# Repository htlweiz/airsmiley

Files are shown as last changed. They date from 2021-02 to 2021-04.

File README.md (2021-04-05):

# Air Smiley: eCO2 measurement box
A small-ish and simple box to measure
- eCO2 with a CCS811 sensor
- Temperature and Humidity with a DHT22 sensor

using a Wemos D1 mini (or clone) with visualization on a
- 0.96" I2C OLED (SSD1306 based)
- NeoPixel compatible RGB LED ring (WS2812B)

The thresholds are set according to [REHVA's recommendations for schools](https://www.rehva.eu/fileadmin/user_upload/REHVA_COVID-19_guidance_document_School_guidance_25112020.pdf).

## User Manual
A (german) user manual is available [here](AIR%20SMILEY.pdf).

## Burn-In
For full sensor accuracy, according to the [datasheet](https://www.sciosense.com/wp-content/uploads/2020/01/CCS811-Datasheet.pdf), the device first needs a "burn-in" phase of 48 operating hours. 

## Run-In
After the "burn-in" phase, the values are considered accurate after a "run-in" time of 20 minutes after power on. Make sure you expose the sensor to clean air throughout the run-in or shortly afterwards to correctly set the baseline (low CO2) for correct sensor readings.

## Flashing
- Install the newest [ESP8266 support](https://www.heise.de/ct/artikel/Arduino-IDE-installieren-und-fit-machen-fuer-ESP8266-und-ESP32-4130814.html)
- Add the following libraries (using the built-in library manager, *Tools –> Manage Libraries...*)
  - NeoPixelBus by Makuna (LGPL-3.0 License)
  - Adafruit CCS811 (MIT License)
  - DHT sensor library by Adafruit (MIT License)
  - Adafruit SSD1306 (BSD License)

## PCB
The PCB has been designed with KiCad and uses the corresponding [libraries](https://kicad.org/libraries/) which are available under the [Creative Commons CC-BY-SA 4.0 License](https://creativecommons.org/licenses/by-sa/4.0/legalcode). Additionally, a [footprint](https://github.com/rubienr/wemos-d1-mini-kicad) made by [rubienr](https://github.com/rubienr) is used.

The PCB is designed to be screwed into a case available at [aliexpress](https://de.aliexpress.com/item/4000068796385.html?spm=a2g0s.9042311.0.0.52614c4dDeY8Wv).

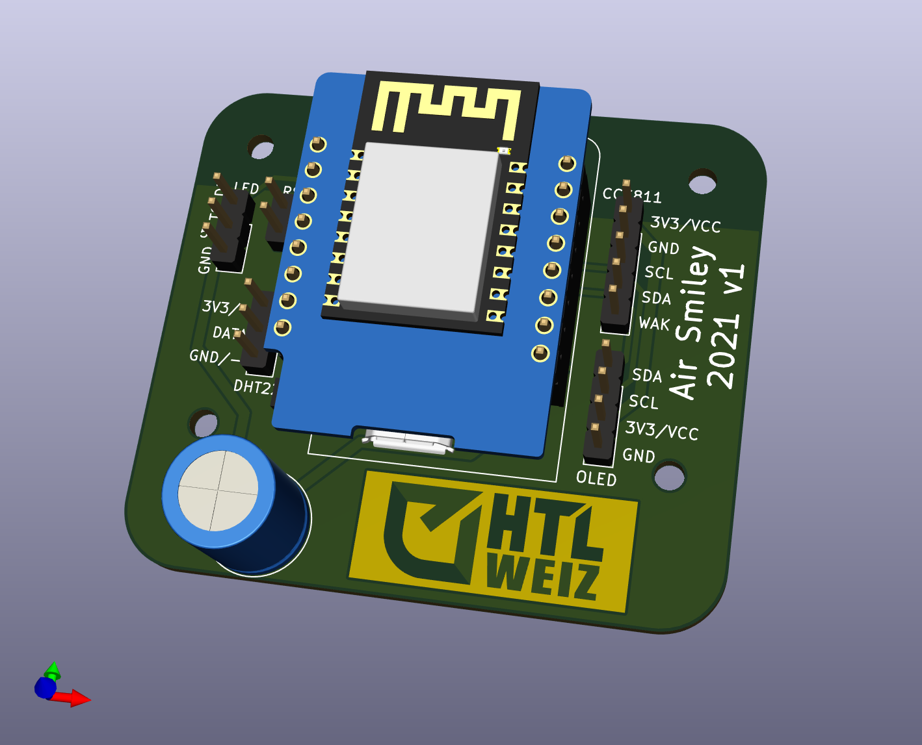
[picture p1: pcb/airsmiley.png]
PCB PCB rendering

1

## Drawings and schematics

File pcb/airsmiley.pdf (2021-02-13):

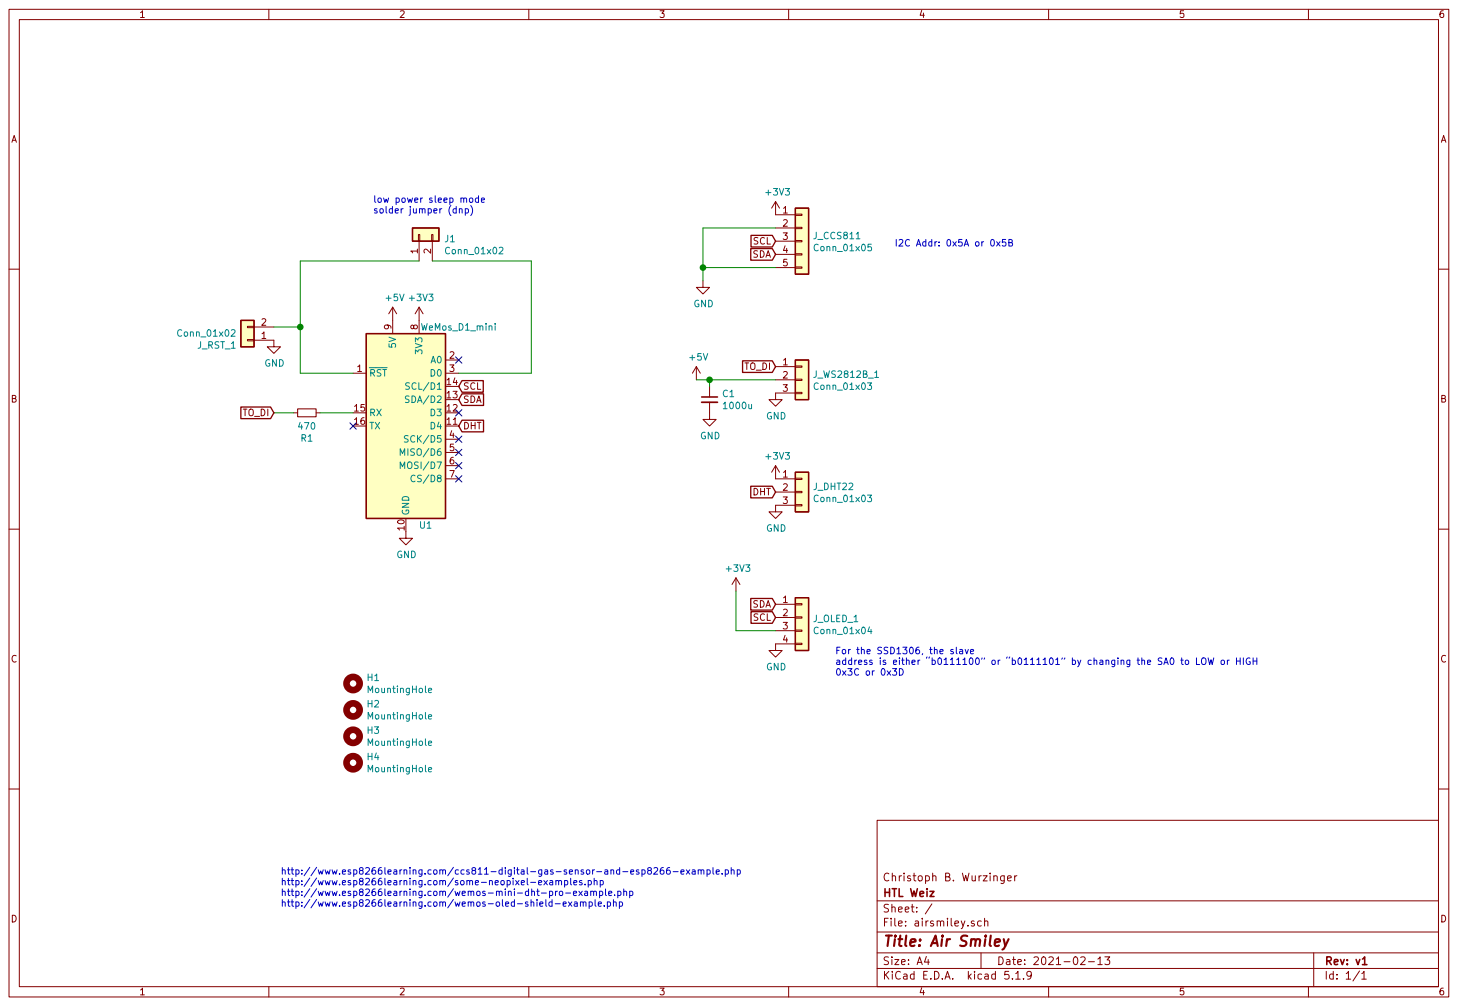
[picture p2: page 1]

low power sleep mode

File: airsmiley.sch Sheet: / HTL Weiz Christoph B. Wurzinger R1

address is either b0111100 or b0111101 by changing the SA0 to LOW or HIGH

http://www.esp8266learning.com/ccs811-digital-gas-sensor-and-esp8266-example.php
http://www.esp8266learning.com/some-neopixel-examples.php
http://www.esp8266learning.com/wemos-mini-dht-pro-example.php
http://www.esp8266learning.com/wemos-oled-shield-example.php

Id: 1/1 Title: Air Smiley

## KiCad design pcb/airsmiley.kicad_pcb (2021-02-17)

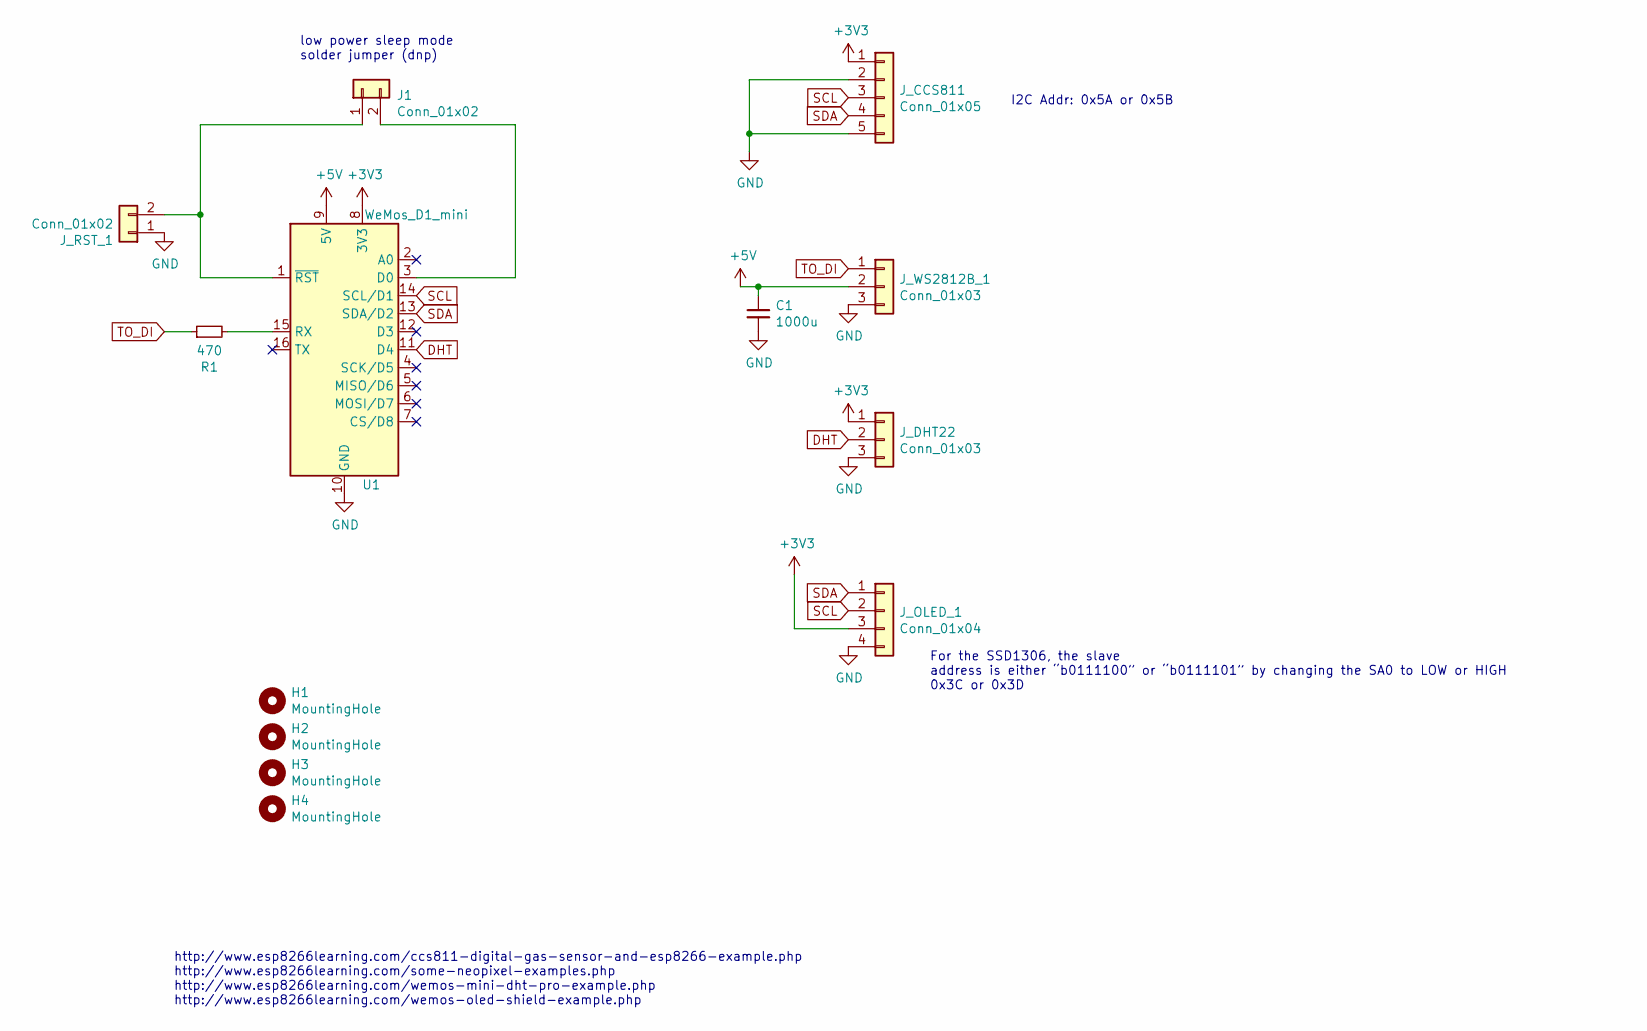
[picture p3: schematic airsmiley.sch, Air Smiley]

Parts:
C1: 1000u; C_Radial_D10.0mm_H12.5mm_P5.00mm
H1, H2, H3, H4: MountingHole; MountingHole_2.7mm_M2.5
J1: Conn_01x02; PinHeader_1x02_P2.54mm_Vertical
J_CCS811: Conn_01x05; PinHeader_1x05_P2.54mm_Vertical
J_DHT22: Conn_01x03; PinHeader_1x03_P2.54mm_Vertical
J_OLED_1: Conn_01x04; PinHeader_1x04_P2.54mm_Vertical
J_RST_1: Conn_01x02; PinHeader_1x02_P2.54mm_Vertical
J_WS2812B_1: Conn_01x03; PinHeader_1x03_P2.54mm_Vertical
R1: 470; R_Axial_DIN0207_L6.3mm_D2.5mm_P10.16mm_Horizontal
U1: WeMos_D1_mini; WEMOS_D1_mini_light

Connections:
+3V3: J_CCS811.1, J_DHT22.1, J_OLED_1.3, U1.8 (3V3)
+5V: C1.1, J_WS2812B_1.2, U1.9 (5V)
DHT: J_DHT22.2, U1.11 (D4)
GND: C1.2, J_CCS811.2, J_CCS811.5, J_DHT22.3, J_OLED_1.4, J_RST_1.1, J_WS2812B_1.3, U1.10 (GND)
unnamed: J1.1, J_RST_1.2, U1.1 (~RST)
unnamed: J1.2, U1.3 (D0)
unnamed: R1.2, U1.15 (RX)
SCL: J_CCS811.3, J_OLED_1.2, U1.14 (SCL/D1)
SDA: J_CCS811.4, J_OLED_1.1, U1.13 (SDA/D2)
TO_DI: J_WS2812B_1.1, R1.1

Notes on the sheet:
http://www.esp8266learning.com/ccs811-digital-gas-sensor-and-esp8266-example.php http://www.esp8266learning.com/some-neopixel-examples.php http://www.esp8266learning.com/wemos-mini-dht-pro-example.php http://www.esp8266learning.com/wemos-oled-shield-example.php
low power sleep mode solder jumper (dnp)
I2C Addr: 0x5A or 0x5B
For the SSD1306, the slave address is either “b0111100” or “b0111101” by changing the SA0 to LOW or HIGH 0x3C or 0x3D

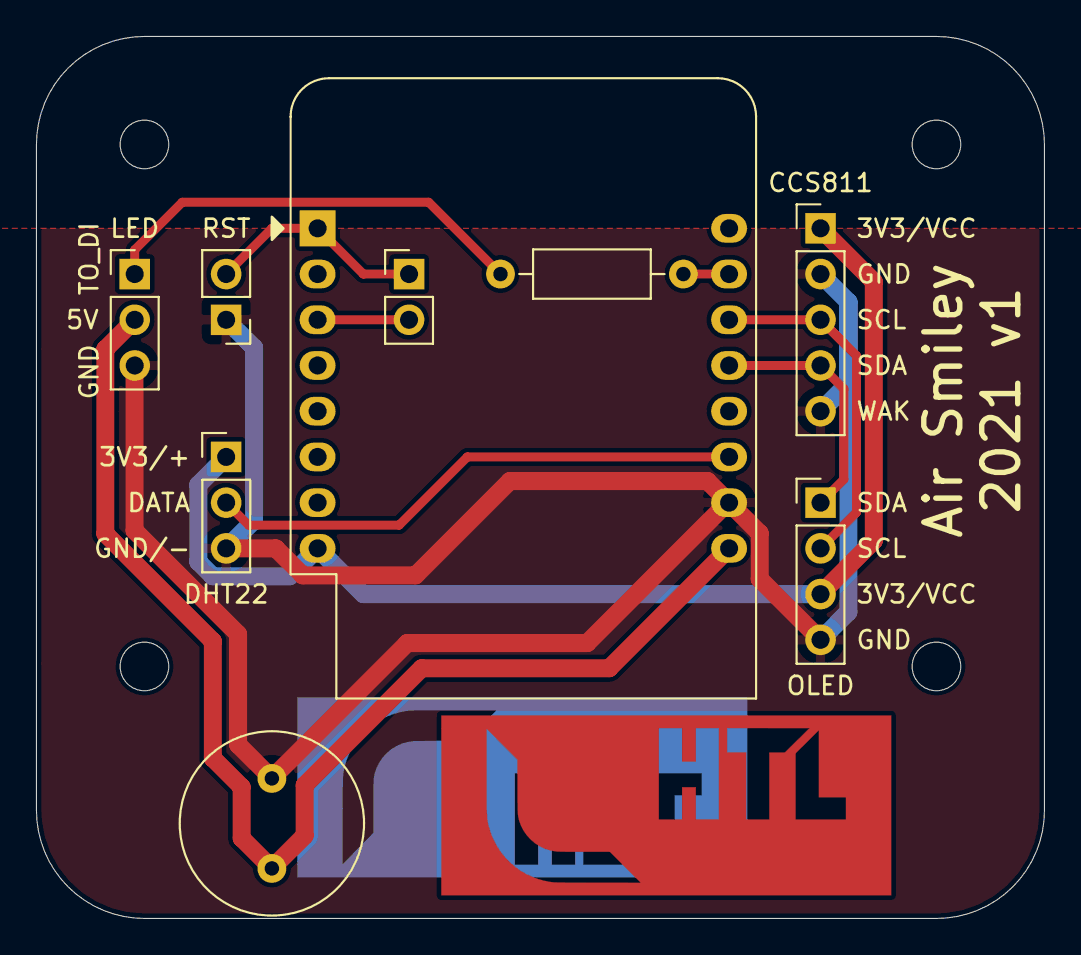
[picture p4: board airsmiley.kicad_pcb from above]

Board: 2 copper layers, 56.0 x 49.0 mm, 15 parts (1 on the bottom side), 10 nets.

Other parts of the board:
Ref**: Val**; logo
Ref**#2: Val**; logo

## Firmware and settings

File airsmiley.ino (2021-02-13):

/*
Copyright 2021 HTL Weiz

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
THE SOFTWARE IS PROVIDED "AS IS", WITHOUT WARRANTY OF ANY KIND, EXPRESS OR
IMPLIED, INCLUDING BUT NOT LIMITED TO THE WARRANTIES OF MERCHANTABILITY,
FITNESS FOR A PARTICULAR PURPOSE AND NONINFRINGEMENT. IN NO EVENT SHALL THE
AUTHORS OR COPYRIGHT HOLDERS BE LIABLE FOR ANY CLAIM, DAMAGES OR OTHER
LIABILITY, WHETHER IN AN ACTION OF CONTRACT, TORT OR OTHERWISE, ARISING FROM,
OUT OF OR IN CONNECTION WITH THE SOFTWARE OR THE USE OR OTHER DEALINGS IN THE
SOFTWARE.
*/

#include "Adafruit_CCS811.h"
#include "DHT.h"
#include <Adafruit_GFX.h>
#include <Adafruit_SSD1306.h>
#include <NeoPixelBus.h>
#include <SPI.h>
#include <Wire.h>

/***********************************************************************
   CO2 Thresholds (ppm).
***********************************************************************/
// Recommendation from REHVA (Federation of European Heating, Ventilation and
// Air Conditioning associations, rehva.eu) for preventing COVID-19 aerosol
// spread especially in schools:
// - warn: 800 (yellow/orange), critical: 1000 (red)
// (https://www.rehva.eu/fileadmin/user_upload/REHVA_COVID-19_guidance_document_School_guidance_25112020.pdf)

#define CO2_WARN_PPM 800
#define CO2_CRITICAL_PPM 1000

/***********************************************************************
   LED ring: NeoPixelBus Setup
***********************************************************************/
const uint16_t PixelCount = 8;
const uint16_t colorSaturation = 10;

NeoPixelBus<NeoGrbFeature, Neo800KbpsMethod> ring(PixelCount, -1);

RgbColor red(colorSaturation, 0, 0);
RgbColor green(0, colorSaturation, 0);
RgbColor orange(colorSaturation, colorSaturation / 2, 0);
RgbColor white(colorSaturation);
RgbColor black(0);

/***********************************************************************
   eCO2 sensor: CCS811 Setup
***********************************************************************/
Adafruit_CCS811 ccs;

/***********************************************************************
   Temperature and Humidity sensor: DHT22 Setup
***********************************************************************/
#define DHTPIN 2
#define DHTTYPE DHT22

DHT dht(DHTPIN, DHTTYPE);

/***********************************************************************
   OLED display: SSD1306 Setup
***********************************************************************/
#define SCREEN_WIDTH 128 // OLED display width, in pixels
#define SCREEN_HEIGHT 64 // OLED display height, in pixels

// Declaration for an SSD1306 display connected to I2C (SDA, SCL pins)
#define OLED_RESET -1 // Reset pin # (or -1 if sharing Arduino reset pin)
Adafruit_SSD1306 display(SCREEN_WIDTH, SCREEN_HEIGHT, &Wire, OLED_RESET);

/***********************************************************************
   System Startup
***********************************************************************/
void setup() {
  Serial.begin(115200);
  Serial.println(F("\nStarting up"));

  Serial.println(F("Bringing up eCO2 sensor"));
  if (!ccs.begin(0x5a)) {
    Serial.println("FAILED to start eCO2 sensor! Please check your wiring.");
  }
  ccs.setDriveMode(CCS811_DRIVE_MODE_1SEC);

  Serial.println(F("Bringing up display"));
  if (!display.begin(SSD1306_SWITCHCAPVCC, 0x3C)) {
    Serial.println(F("FAILED display allocation"));
  }
  display.setRotation(2);
  display.clearDisplay();
  display.display();

  Serial.println(F("Bringing up LEDs"));
  ring.Begin();
  for (int i = 0; i < PixelCount; i++) {
    ring.SetPixelColor(i, white);
  }
  ring.Show();

  Serial.println(F("Bringing up temperaturea and humidity sensor"));
  dht.begin();

  Serial.println(F("Setup complete."));
}

/***********************************************************************
   Main Loop
***********************************************************************/
void loop() {
  Serial.println(F("looping"));

  float humidity = dht.readHumidity();
  float temperature = dht.readTemperature();

  static float eco2 = 0;
  static float tvoc = 0;

  if (ccs.available()) {
    ccs.setEnvironmentalData(humidity, temperature);
    Serial.print(F("ccs.readData: "));
    Serial.println(ccs.readData());
    eco2 = ccs.geteCO2();
    tvoc = ccs.getTVOC();
  }

  displayData(temperature, humidity, eco2, tvoc);

  delay(500);
}

/***********************************************************************
   Visualize Data
***********************************************************************/
void displayData(float temp, float hum, uint32_t eco2, uint32_t tvoc) {
  const int xshift = 6;
  const int yshift = 2;
  char *fills[] = {"    ", "   ", "  ", " ", ""};
  char *temp_fill = fills[(int)log10(temp)];
  char *hum_fill = fills[(int)log10(hum)];
  char *eco2_fill = fills[(int)log10(eco2)];
  char *tvoc_fill = fills[(int)log10(tvoc)];

  display.clearDisplay();
  display.setTextSize(2);
  display.setTextColor(SSD1306_WHITE); // Draw white text
  display.setCursor(xshift, 0 + yshift / 2);
  display.print(temp, 1);
  display.print((char)247);
  display.print(F("C "));
  display.print(hum, 0);
  display.println(F("%"));
  display.setTextSize(4);
  display.setCursor(xshift, 16 + yshift);
  display.print(eco2_fill);
  display.print(eco2);
  display.setCursor(xshift, 24 + yshift);
  display.setTextSize(1);
  display.print(F("eCO2"));
  display.setCursor(xshift, 32 + yshift);
  display.print(F("ppm"));

  display.setCursor(xshift, 48 + 1);
  display.setTextSize(1);
  display.print(F("eTVOC"));
  display.setCursor(xshift, 56);
  display.print(F("ppb"));
  display.setCursor(64, 48 + 1);
  display.setTextSize(2);
  display.print(tvoc_fill);
  display.print(tvoc);
  display.display();

  Serial.print(F("\nHTL Weiz "));
  Serial.println(F("Air Smiley"));
  Serial.print(F("T(°C): "));
  Serial.println(temp, 1);
  Serial.print(F("H(%): "));
  Serial.println(hum, 1);
  Serial.print(F("eTVOC(ppb): "));
  Serial.println(tvoc);
  Serial.print(F("eCO2(ppm): "));
  Serial.println(eco2);
  Serial.print(F("baseline: "));
  Serial.println(ccs.getBaseline());
  Serial.print(F("current(uA): "));
  Serial.println(ccs.getCurrentSelected());
  Serial.print(F("adc: "));
  Serial.println(ccs.getRawADCreading());

  RgbColor color = green;
  if (eco2 >= CO2_WARN_PPM) {
    color = orange;
    display.invertDisplay(true);
  } else {
    display.invertDisplay(false);
  }
  if (eco2 >= CO2_CRITICAL_PPM) {
    color = red;
  }

  for (int i = 0; i < PixelCount; i++) {
    ring.SetPixelColor(i, color);
  }
  ring.Show();
}

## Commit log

2020-11-27 added schematic and pcb printout
2020-11-27 added 3d pcb view
2020-12-13 more details on sensor run-in
2021-02-13 Renamed to "Air Smiley"
    [airsmiley-B_Cu.gbr, airsmiley-B_Mask.gbr, airsmiley-B_Paste.gbr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]
2021-02-13 rename to "Air Smiley" in arduino code
2021-02-17 minor pcb changes
    [airsmiley-B_Cu.gbr, airsmiley-B_Mask.gbr, airsmiley-B_Paste.gbr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]
